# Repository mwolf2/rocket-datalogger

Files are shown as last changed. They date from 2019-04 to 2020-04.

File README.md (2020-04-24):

# rocket-datalogger
Linux-based datalogger for amateur rockets. School project by Max Wolf and Emmett Hart.
Goal -- Make a datalogger that enables amateur rockets to act as low-altitude sounding rockets for meteorological and kinematic data.
Current Status -- Done (for now, might reopen at some point in the future); Contributions Welcome! (please make a pull request)

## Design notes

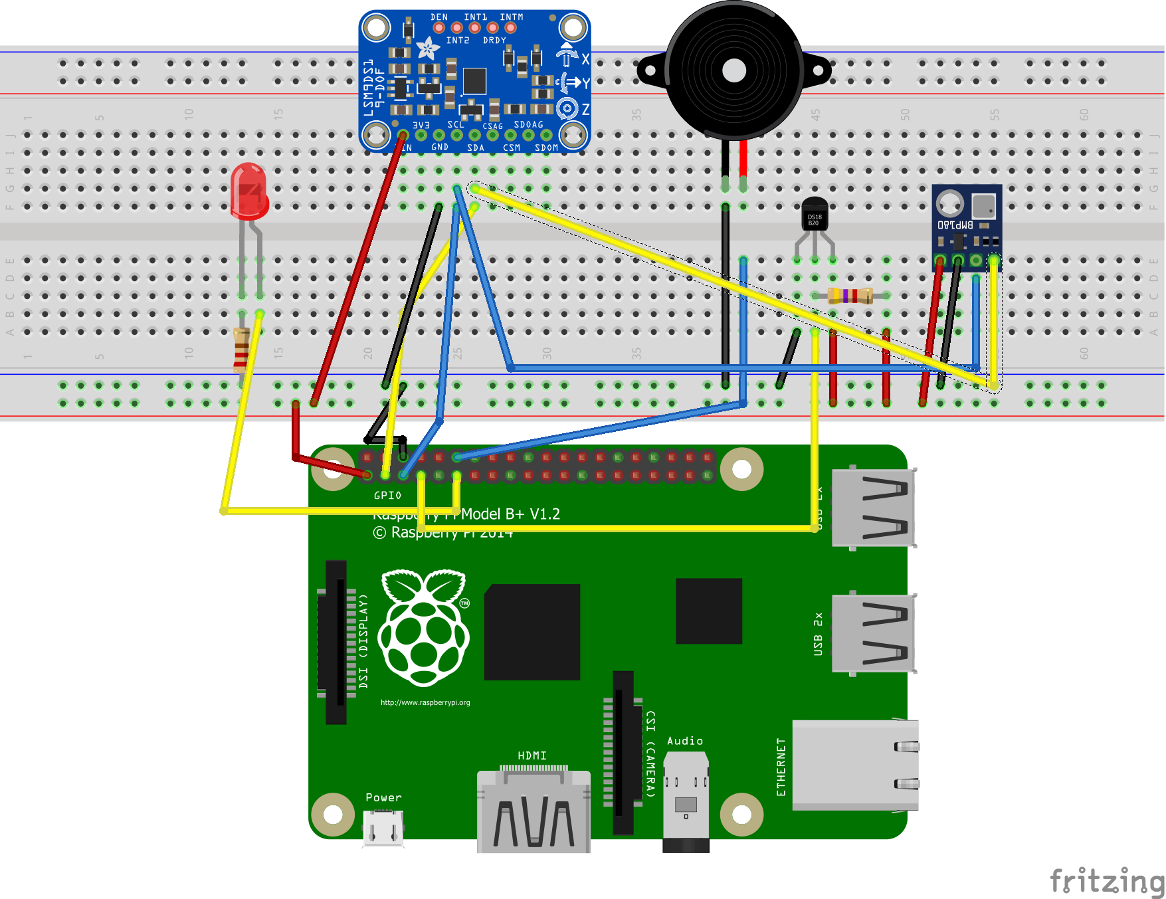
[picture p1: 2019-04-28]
Images/rpi_datalogger_bb.png

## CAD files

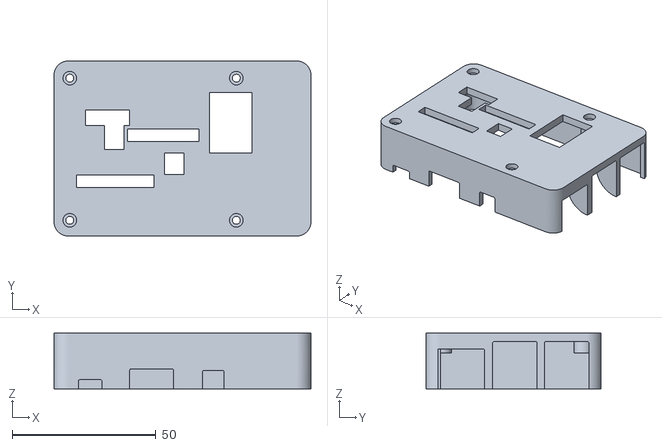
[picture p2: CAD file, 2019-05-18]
3D Models/RPi_Cover_data-logger v4.stl
89.5 x 61.0 x 19.5

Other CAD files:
3D Models/RPi_Cover_data-logger v3.stl
3D Models/RPi_Cover_data-logger v3.f3d
3D Models/RPi_Cover_data-logger v4.f3d

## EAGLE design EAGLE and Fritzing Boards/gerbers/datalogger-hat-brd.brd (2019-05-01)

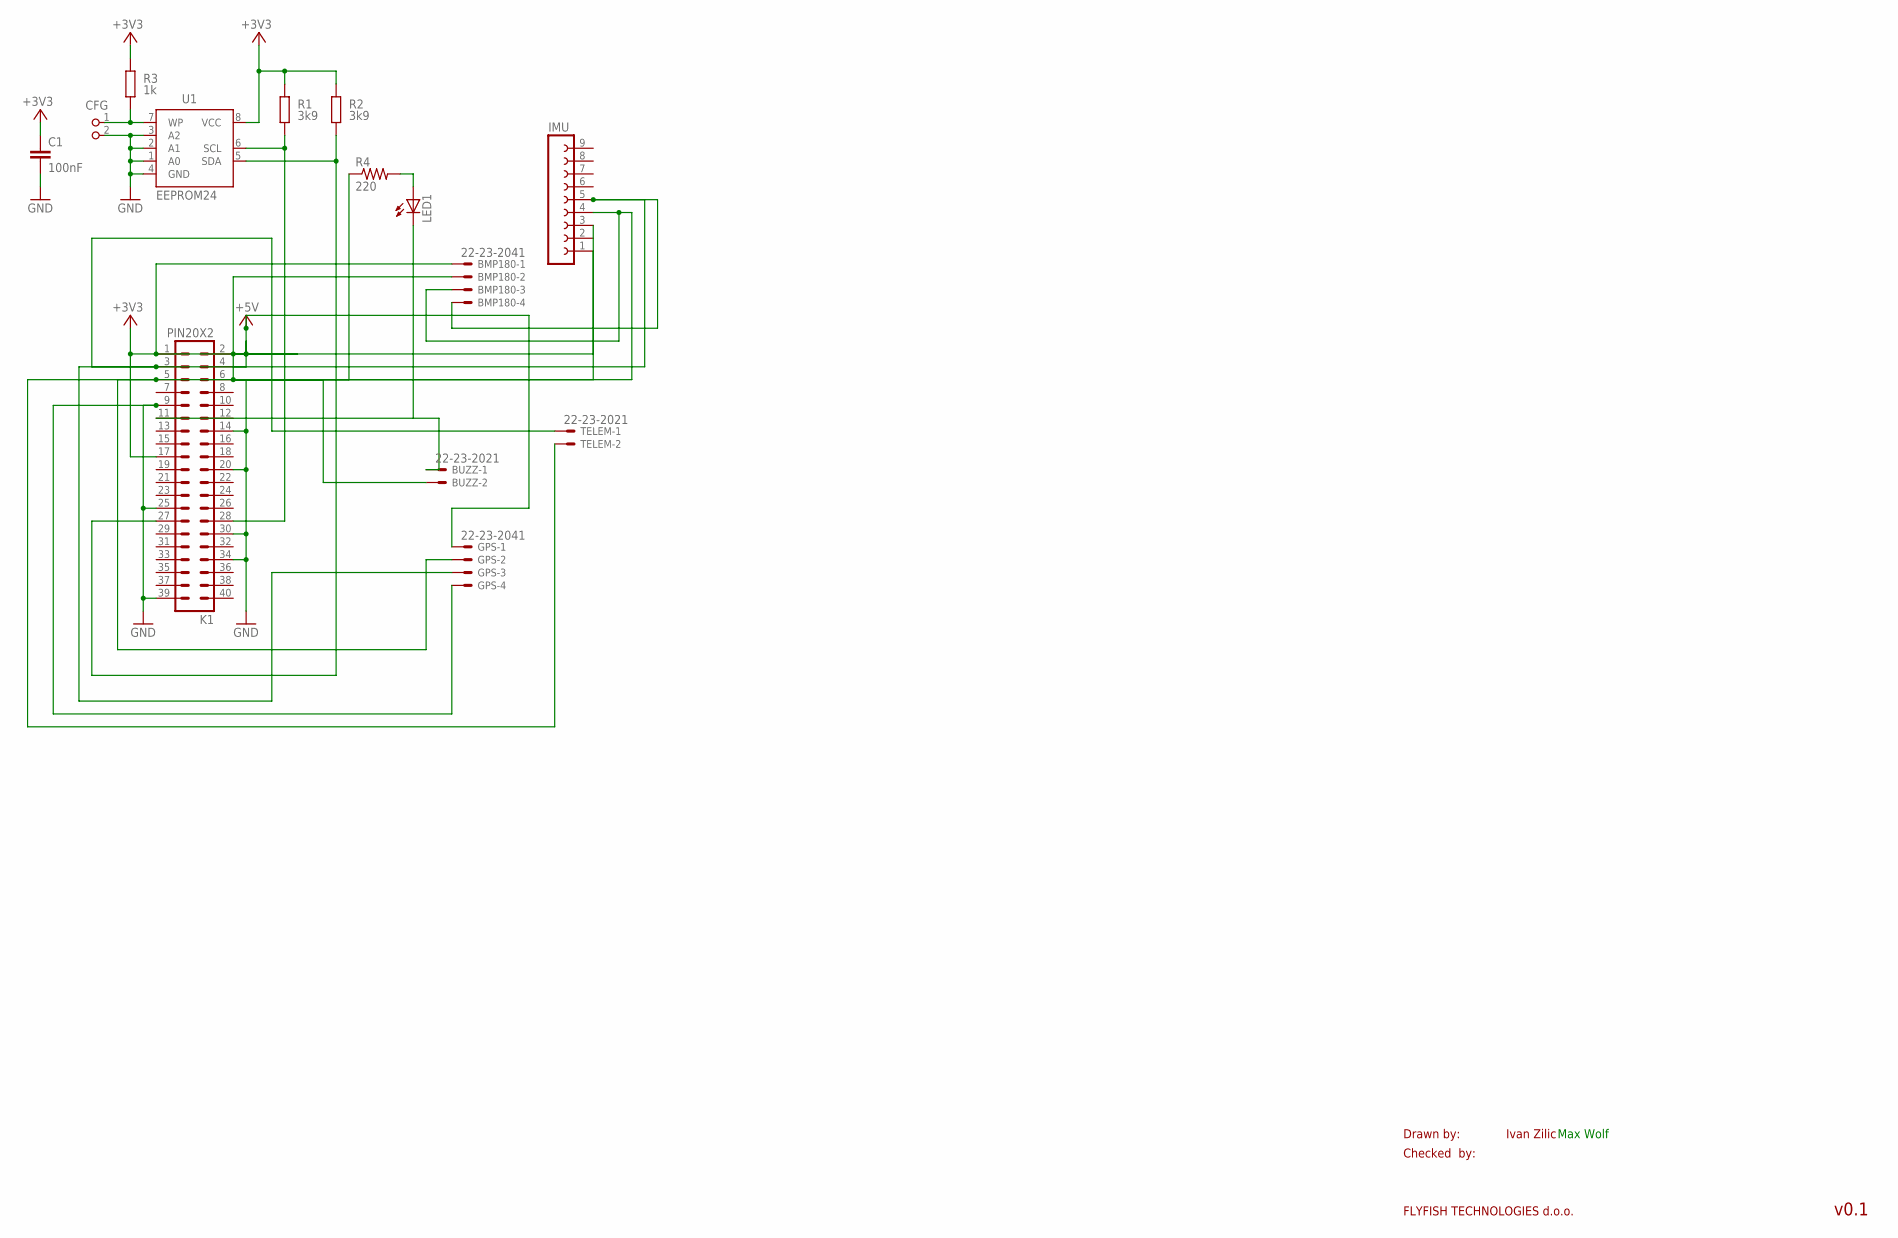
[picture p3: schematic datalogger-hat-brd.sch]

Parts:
BMP180: 22-23-2041
BUZZ: 22-23-2021
C1: 100nF; C0805K
CFG: PIN2_100; PIN_W_2
GPS: 22-23-2041
IMU: FE09-1; FE09
K1: PIN20X2; PIN_20X2
LED1: LED_ELD260; LED_LD260
R1, R2: 3k9; M0805; TOLERANCE 5%
R3: 1k; M0805; TOLERANCE 5%
R4: 220; 0204/5
TELEM: 22-23-2021
U1: EEPROM24; SOIC8

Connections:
+3V3: BMP180.1, C1.1, IMU.1, K1.1, K1.17, R1.2, R2.2, R3.2, U1.8 (VCC)
+5V: GPS.1, K1.2, K1.4
GND: BMP180.2, BUZZ.2, C1.2, CFG.2, GPS.4, IMU.3, K1.6, K1.9, K1.14, K1.20, K1.25, K1.30, K1.34, K1.39, R4.1, U1.1 (A0), U1.2 (A1), U1.3 (A2), U1.4 (GND)
unnamed: K1.28, R1.1, U1.6 (SCL)
unnamed: K1.27, R2.1, U1.5 (SDA)
unnamed: CFG.1, R3.1, U1.7 (WP)
unnamed: BMP180.4, GPS.3, IMU.5, K1.3, TELEM.1
unnamed: BMP180.3, GPS.2, IMU.4, K1.5, TELEM.2
unnamed: BUZZ.1, K1.11, LED1.K (C)
unnamed: LED1.A, R4.2

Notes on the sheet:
Drawn by:
Checked by:
FLYFISH TECHNOLOGIES d.o.o.
Ivan Zilic
v0.1
Max Wolf

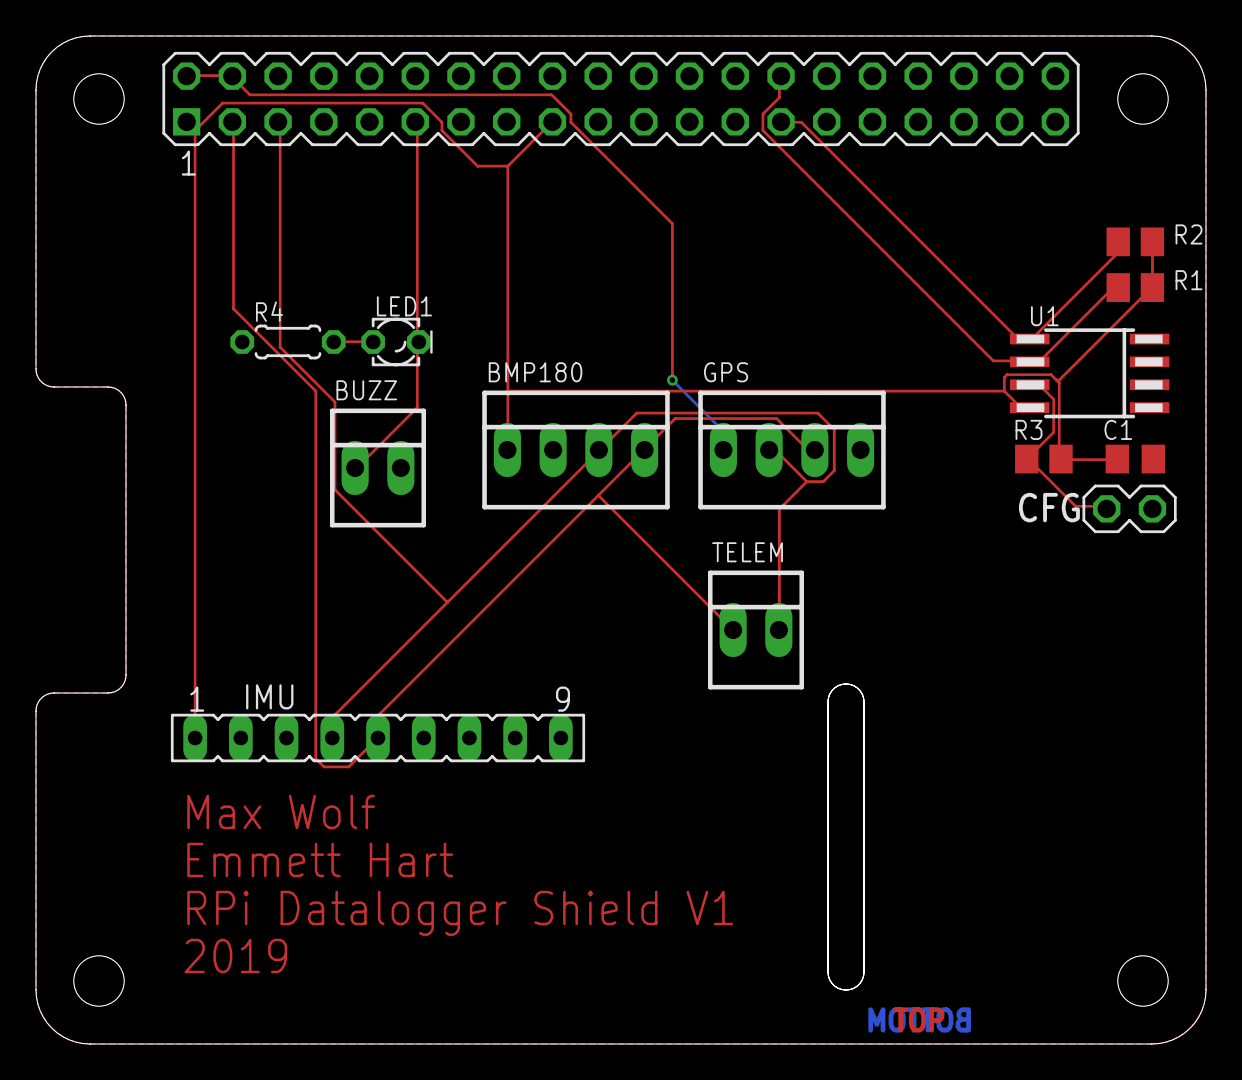
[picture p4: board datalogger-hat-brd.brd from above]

Board: 2 copper layers, 65.0 x 56.0 mm, 14 parts (0 on the bottom side), 10 nets.

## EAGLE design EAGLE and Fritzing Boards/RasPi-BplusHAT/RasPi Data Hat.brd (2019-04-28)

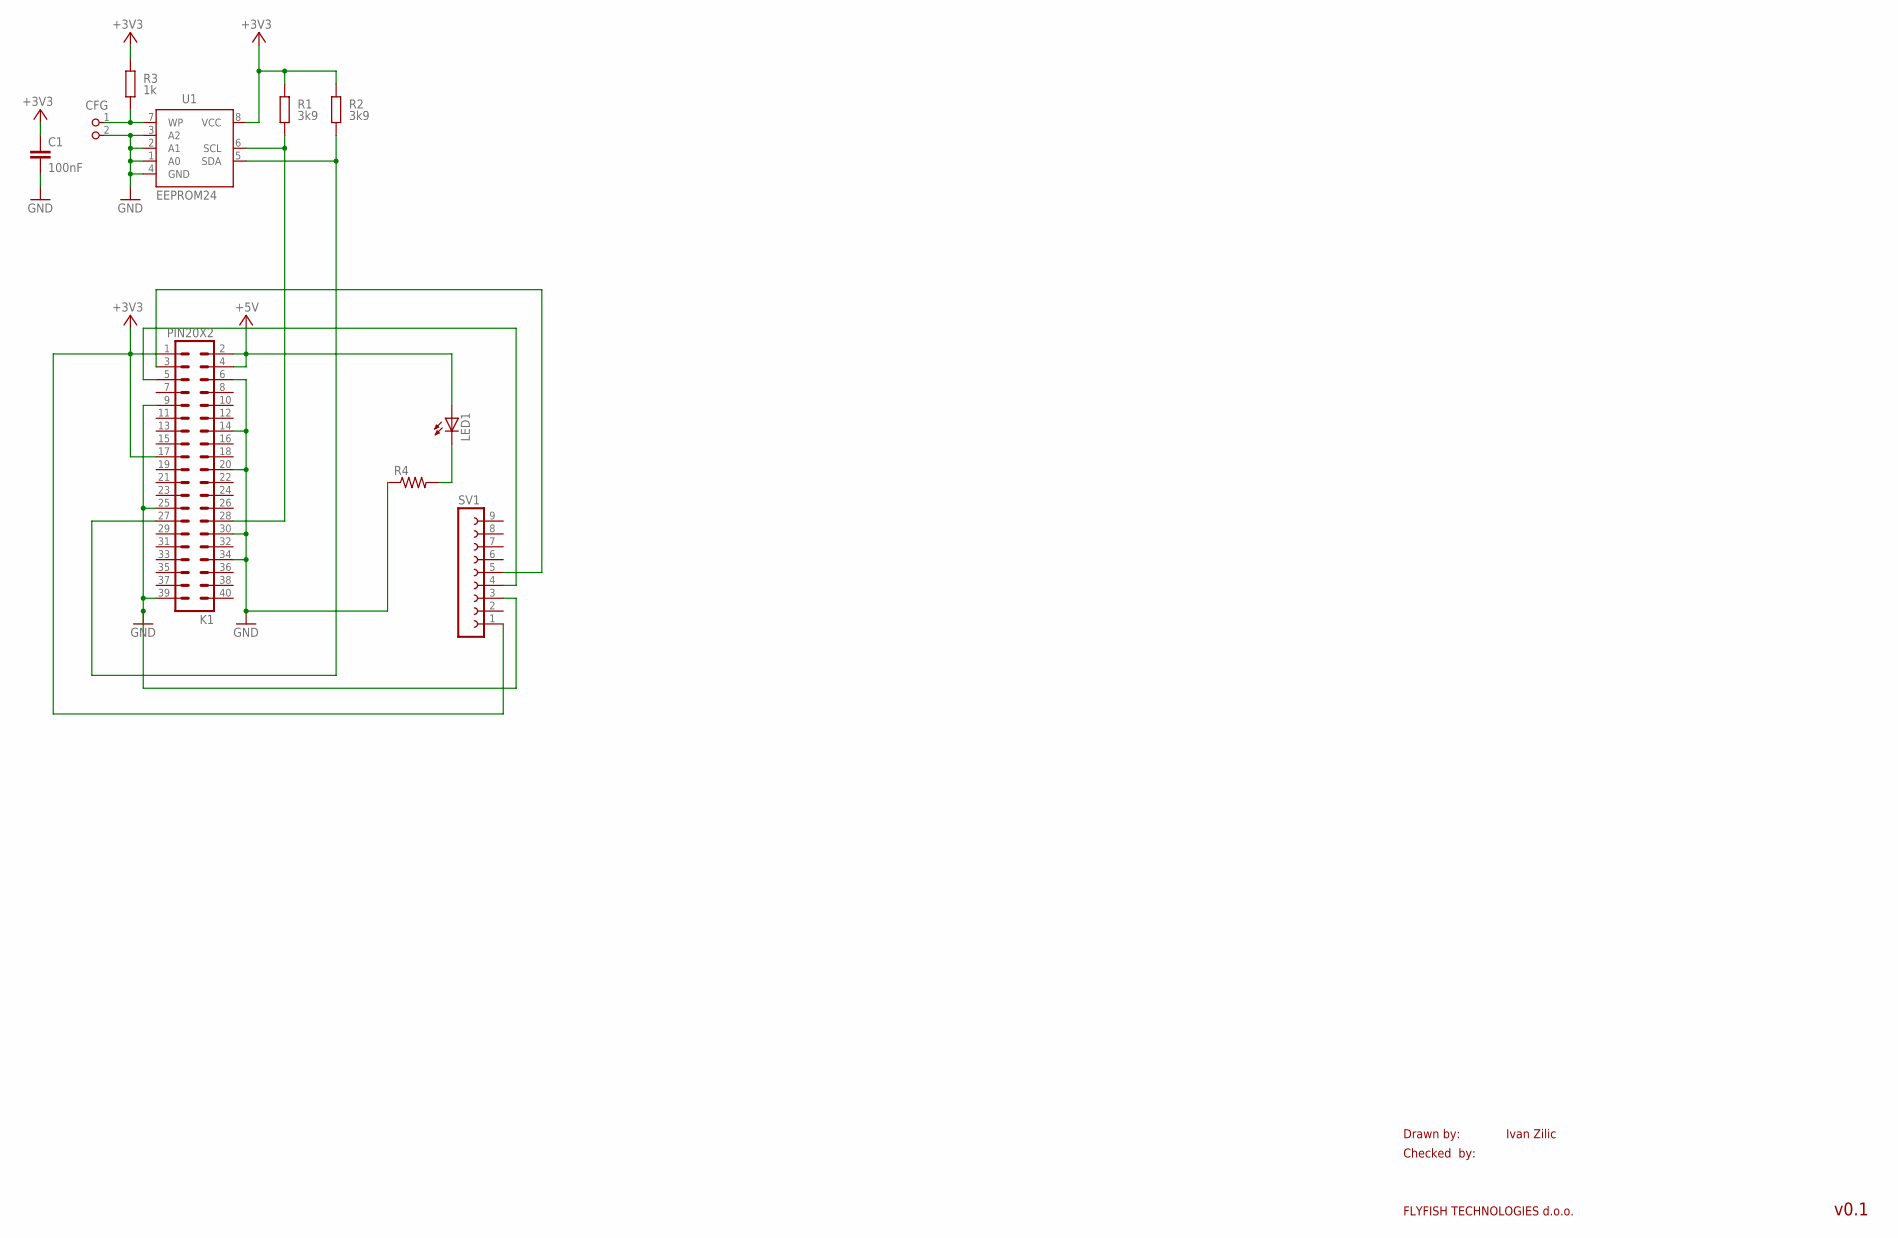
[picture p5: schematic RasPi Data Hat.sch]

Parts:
C1: 100nF; C0805K
CFG: PIN2_100; PIN_W_2
K1: PIN20X2; PIN_20X2
LED1: LED3MM
R1, R2: 3k9; M0805; TOLERANCE 5%
R3: 1k; M0805; TOLERANCE 5%
R4: R-US_0204/5; 0204/5
SV1: FE09-1; FE09
U1: EEPROM24; SOIC8

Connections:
+3V3: C1.1, K1.1, K1.17, R1.2, R2.2, R3.2, SV1.1, U1.8 (VCC)
+5V: K1.2, K1.4, LED1.A
GND: C1.2, CFG.2, K1.6, K1.9, K1.14, K1.20, K1.25, K1.30, K1.34, K1.39, R4.1, SV1.3, U1.1 (A0), U1.2 (A1), U1.3 (A2), U1.4 (GND)
unnamed: K1.28, R1.1, U1.6 (SCL)
unnamed: K1.27, R2.1, U1.5 (SDA)
unnamed: CFG.1, R3.1, U1.7 (WP)
unnamed: LED1.K (C), R4.2
unnamed: K1.5, SV1.4
unnamed: K1.3, SV1.5

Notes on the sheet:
Drawn by:
Checked by:
FLYFISH TECHNOLOGIES d.o.o.
Ivan Zilic
v0.1

Board: 2 copper layers, 10 parts (0 on the bottom side), 9 nets, no tracks yet.

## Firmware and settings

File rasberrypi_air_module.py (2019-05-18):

#Import necessary libraries
#RPi.GPIO necessary to use GPIO pins on RPi
import RPi.GPIO as GPIO
#time library for delays
import time
#smbus necessary to handle I2C communication
import smbus
#subprocess necessary to interact with command line
import subprocess
"""
os necessary to handle interactions with the Pi's operating system.
Additionally, the os library will allow us to make directories, change
directories, handle files, etc.
"""
import os
#datetime necessary to put file timestamps in human-readable format
#Can't use datetime.now() with import datetime. Platform-specific?
from datetime import datetime
#re necessary to get search for text and use it
import re
#BMP180 library
from Adafruit_BMP085 import BMP085
#ctypes for LSM9DS1 library
from ctypes import *
#csv necessary to create csv files
import csv
#itertools needed for islice to read specific lines of CSV
from itertools import islice

#SETUP~~~~~~~~~~~~~~~~~~~~~~~~~~~~~~~~~~~~~~~~~~~~~~~~~~~~~~~~~~~~~~~~~~~~~~~~~

#Pin definitions
ledPin = 17
sdaPin = 2
sclPin = 3
piezoPin = 12

#I2C Port Setup (for communication with Lora boards)
i2c = smbus.SMBus(1)

#I2C Addresses
#Barometer
bmp = BMP085(0x77, 1)
temp = bmp.read_temperature()
pressure = bmp.read_pressure()
asl = bmp.read_altitude() #0m pressure changeable via telemetry later
#IMU
#This code snippet from Akimach on Github:
path = "../lib/liblsm9ds1cwrapper.so"
lib = cdll.LoadLibrary(path)

lib.lsm9ds1_create.argtypes = []
lib.lsm9ds1_create.restype = c_void_p

lib.lsm9ds1_begin.argtypes = [c_void_p]
lib.lsm9ds1_begin.restype = None

lib.lsm9ds1_calibrate.argtypes = [c_void_p]
lib.lsm9ds1_calibrate.restype = None

lib.lsm9ds1_gyroAvailable.argtypes = [c_void_p]
lib.lsm9ds1_gyroAvailable.restype = c_int
lib.lsm9ds1_accelAvailable.argtypes = [c_void_p]
lib.lsm9ds1_accelAvailable.restype = c_int
lib.lsm9ds1_magAvailable.argtypes = [c_void_p]
lib.lsm9ds1_magAvailable.restype = c_int

lib.lsm9ds1_readGyro.argtypes = [c_void_p]
lib.lsm9ds1_readGyro.restype = c_int
lib.lsm9ds1_readAccel.argtypes = [c_void_p]
lib.lsm9ds1_readAccel.restype = c_int
lib.lsm9ds1_readMag.argtypes = [c_void_p]
lib.lsm9ds1_readMag.restype = c_int

lib.lsm9ds1_getGyroX.argtypes = [c_void_p]
lib.lsm9ds1_getGyroX.restype = c_float
lib.lsm9ds1_getGyroY.argtypes = [c_void_p]
lib.lsm9ds1_getGyroY.restype = c_float
lib.lsm9ds1_getGyroZ.argtypes = [c_void_p]
lib.lsm9ds1_getGyroZ.restype = c_float

lib.lsm9ds1_getAccelX.argtypes = [c_void_p]
lib.lsm9ds1_getAccelX.restype = c_float
lib.lsm9ds1_getAccelY.argtypes = [c_void_p]
lib.lsm9ds1_getAccelY.restype = c_float
lib.lsm9ds1_getAccelZ.argtypes = [c_void_p]
lib.lsm9ds1_getAccelZ.restype = c_float

lib.lsm9ds1_getMagX.argtypes = [c_void_p]
lib.lsm9ds1_getMagX.restype = c_float
lib.lsm9ds1_getMagY.argtypes = [c_void_p]
lib.lsm9ds1_getMagY.restype = c_float
lib.lsm9ds1_getMagZ.argtypes = [c_void_p]
lib.lsm9ds1_getMagZ.restype = c_float

lib.lsm9ds1_calcGyro.argtypes = [c_void_p, c_float]
lib.lsm9ds1_calcGyro.restype = c_float
lib.lsm9ds1_calcAccel.argtypes = [c_void_p, c_float]
lib.lsm9ds1_calcAccel.restype = c_float
lib.lsm9ds1_calcMag.argtypes = [c_void_p, c_float]
lib.lsm9ds1_calcMag.restype = c_float

if __name__ == "__main__":
    imu = lib.lsm9ds1_create()
    lib.lsm9ds1_begin(imu)
    if lib.lsm9ds1_begin(imu) == 0:
        print("Failed to communicate with LSM9DS1.")
        quit()
    lib.lsm9ds1_calibrate(imu)

    while True:
        while lib.lsm9ds1_gyroAvailable(imu) == 0:
            pass
        lib.lsm9ds1_readGyro(imu)
        while lib.lsm9ds1_accelAvailable(imu) == 0:
            pass
        lib.lsm9ds1_readAccel(imu)
        while lib.lsm9ds1_magAvailable(imu) == 0:
            pass
        lib.lsm9ds1_readMag(imu)

        gx = lib.lsm9ds1_getGyroX(imu)
        gy = lib.lsm9ds1_getGyroY(imu)
        gz = lib.lsm9ds1_getGyroZ(imu)

        ax = lib.lsm9ds1_getAccelX(imu)
        ay = lib.lsm9ds1_getAccelY(imu)
        az = lib.lsm9ds1_getAccelZ(imu)

        mx = lib.lsm9ds1_getMagX(imu)
        my = lib.lsm9ds1_getMagY(imu)
        mz = lib.lsm9ds1_getMagZ(imu)

        cgx = lib.lsm9ds1_calcGyro(imu, gx)
        cgy = lib.lsm9ds1_calcGyro(imu, gy)
        cgz = lib.lsm9ds1_calcGyro(imu, gz)

        cax = lib.lsm9ds1_calcAccel(imu, ax)
        cay = lib.lsm9ds1_calcAccel(imu, ay)
        caz = lib.lsm9ds1_calcAccel(imu, az)

        cmx = lib.lsm9ds1_calcMag(imu, mx)
        cmy = lib.lsm9ds1_calcMag(imu, my)
        cmz = lib.lsm9ds1_calcMag(imu, mz)
#End Akimach's code
#Tell console I2C device list is about to be printed
print("I2C Device List:")
#Open terminal, run i2cdetect
geti2c = subprocess.Popen(['i2cdetect', '-y', '1'], stdout=subprocess.PIPE)
#For every match for number, number: anything, number, number found, print it
"""
Add feature that lets RPi check that Lora, baro, and IMU are at certain
addresses
"""
for i in range (0,9):
    line = str(p.stdout.readline())
    
    for match in re.finditer("[0-9][0-9]:.*[0-9][0-9]", line):
        #match.group() is all i2c devices from i2cdetect
        i2cDev = match.group()
        #Parse i2cDev so that we get rid of dashes and spaces
        i2cDevParsed = i2cDev.replace("-", "").replace(" ", "") #Bad syntax
        #Print out the result
        print (i2cDevParsed, "\n")
        
        
#Set up LoraWAN board through I2C
loraAddress = 0x04

def sendByte(x):
    i2c.write_byte(loraAddress, x)
    return -1

def recByte():
    inByte = i2c.read_byte(loraAddress)
    return inByte

sendByte(0)
print ('Sent Lora board "0"')

loraOpenByte = recByte()
print ('Received ', loraOpenByte, ' from Lora board.\n')

if loraOpenByte == 1:
    print ('Connection with Lora board established.')
else:
    print ('No connection to Lora board.')

"""
Set RPi GPIO mode - in this case, we are referring to the RPi's GPIO pins
according to the numbering printed on the motherboard. This is because the
datalogger doesn't use a Pi Wedge or similar device, so it's just easier
this way.
"""
GPIO.setmode(GPIO.BOARD)

print("GPIO mode set to BOARD") #Print GPIO mode to command line

GPIO.setup(ledPin, GPIO.OUT) #LED pin set to output
GPIO.setup(piezoPin, GPIO.OUT) #Piezo pin set to output

#Set up CSV
timestamp = datetime.now().strftime('%Y-%m-%d-%H-%M')
filetime = timestamp.replace("'", "")
dataCSV = "flightdata " + filetime + ".csv" #Set up CSV name for datalogging

titleRow = ['Time', 'Xa', 'Ya', 'Za', 'Xo', 'Yo', 'Zo', 'Mx', 'My', 'Mz', 'Pressure', 'ASL', 
            'AGL', 'Temp']

with open(dataCSV, 'w'):
    writer = csv.writer(dataCSV)
    writer.writerow(titleRow)
    
dataCSV.close()

#Setup is finished! On to the datalogging and telemetry

#Datalogging & Telemetry~~~~~~~~~~~~~~~~~~~~~~~~~~~~~~~~~~~~~~~~~~~~~~~~~~~~~~~
print("Beginning logging and telemetry transmission.")


landed = 0 #Rocket landed -- Controls what is being sent
flightComplete = 0 #Flight complete, datalogging can stop
landTimerStarted = 0
landTimeElapsed = 0

calibration = open('calibration' + datetime.now().strftime('%Y-%m-%d-%H-%M'), 'w')
calibration.write(asl + "\n")
calibration.write()

rowCount = 1;

while (flightComplete == 0):
    
    with open(calibration, "r"):
        calReadAlt = calibration.readline(1)
        agl = asl - calReadAlt
    
    ltime = datetime.now().strftime('%H-%M')
    dataRow = [ltime, cax, cay, caz, cgx, cgy, cgz, cmx, cmy, cmz, pressure,
               asl, agl]
    
    with open(dataCSV, 'a'):
        writer = csv.writer(dataCSV)
        writer.writerow(dataRow)
        rowCount += 1
    
    with open(dataCSV, "r"):
        dataRead = csv.reader(dataCSV, delimiter = ',')
        for row in reversed(dataRead):
            lastAlt = row[12]
            if (lastAlt == asl):
                if (landTimerStarted == 0):
                    landStart = time.time()
                else:
                    landCurrent = time.time()
                    landTimeElapsed = landStart - landCurrent
                    if (landTimeElapsed == 30):
                        flightComplete = 1
                
            else:
                pass

dataCSV.close()

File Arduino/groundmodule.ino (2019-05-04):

#include <U8x8lib.h>
#include <LoRa.h>

String receivedT;
String receivedRSSI;

//GPIO19 - LoRa_MISO
//GPIO18 - LoRa_CS
//GPIO5 - LoRa_SCK
//GPIO27 - LoRa_MOSI
//GPIO14 - LoRa_RST

#define SS  18 //Slave Select
#define RST 14
#define DI0 26

void setup() {

  int counter = 0;
  int conTimer = 0;
  bool conOK = 1;
  Serial.begin(115200);
  while(!Serial);
  LoRa.setPins(SS, RST, DI0);

  while (!LoRa.begin(868E6) && conOK == 1)
  {
    Serial.println(".");
    delay(1000);
    conTimer++;

    if (conTimer > 20)
    {
      conOK = 0;
      Serial.println("No connection to rocket.");
    }
    
  }
  

  LoRa.setSyncWord(0xF3);
  LoRa.beginPacket();
  LoRa.print("OK");
  LoRa.print(counter);
  LoRa.endPacket();

}

void loop() {
  

}

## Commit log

2019-04-27 Add files via upload
    First project commit outside of when repository was created. Includes EAGLE and Fritzing boards, images, and programs as of 4/27/2019 at 11:33AM GMT
2019-04-28 Add files via upload
    Committed more recent files to master branch, and not in .zip format. 5:18PM GMT
    [RasPi Data Hat.brd, RasPi Data Hat.sch, RasPi-BplusHAT.brd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]
2019-05-01 Rename EAGLE and Fritzing Boards/copper_bottom.gbr to EAGLE and Fritzing Boards/gerbers/copper_bottom.gbr
    [copper_bottom.gbr]
2019-05-01 Rename EAGLE and Fritzing Boards/copper_top.gbr to EAGLE and Fritzing Boards/gerbers/copper_top.gbr
    [copper_top.gbr]
2019-05-01 Rename EAGLE and Fritzing Boards/datalogger-hat-brd.brd to EAGLE and Fritzing Boards/gerbers/datalogger-hat-brd.brd
    [datalogger-hat-brd.brd]
2019-05-01 Rename EAGLE and Fritzing Boards/datalogger-hat-brd.sch to EAGLE and Fritzing Boards/gerbers/datalogger-hat-brd.sch
    [datalogger-hat-brd.sch]
2019-05-01 Rename EAGLE and Fritzing Boards/drills.xln to EAGLE and Fritzing Boards/gerbers/drills.xln
    [drills.xln]
2019-05-01 Rename EAGLE and Fritzing Boards/gerber_job.gbrjob to EAGLE and Fritzing Boards/gerbers/gerber_job.gbrjob
    [gerber_job.gbrjob]
2019-05-01 Rename EAGLE and Fritzing Boards/profile.gbr to EAGLE and Fritzing Boards/gerbers/profile.gbr
    [profile.gbr]
2019-05-01 Rename EAGLE and Fritzing Boards/silkscreen_bottom.gbr to EAGLE and Fritzing Boards/gerbers/silkscreen_bottom.gbr
    [silkscreen_bottom.gbr]
2019-05-01 Rename EAGLE and Fritzing Boards/silkscreen_top.gbr to EAGLE and Fritzing Boards/gerbers/silkscreen_top.gbr
    [silkscreen_top.gbr]
2019-05-01 Rename EAGLE and Fritzing Boards/soldermask_bottom.gbr to EAGLE and Fritzing Boards/gerbers/soldermask_bottom.gbr
    [soldermask_bottom.gbr]
2019-05-01 Rename EAGLE and Fritzing Boards/soldermask_top.gbr to EAGLE and Fritzing Boards/gerbers/soldermask_top.gbr
    [soldermask_top.gbr]
2019-05-01 Rename EAGLE and Fritzing Boards/solderpaste_bottom.gbr to EAGLE and Fritzing Boards/gerbers/solderpaste_bottom.gbr
    [solderpaste_bottom.gbr]
2019-05-01 Rename EAGLE and Fritzing Boards/solderpaste_top.gbr to EAGLE and Fritzing Boards/gerbers/solderpaste_top.gbr
    [solderpaste_top.gbr]
2019-05-10 Updated raspberrypi_air_module.py to export CSV File and add lib/
2019-05-10 finished CSV export support, need to fix AGL logging
    [rasberrypi_air_module.py]
2019-05-10 Forgot to run program to test after last commit, accidentally removed dependancy, Although I don't think we need that section of code anyways (calibration file)
2019-05-11 added Raspberry Pi case
    [RPi_Cover_data-logger v3.f3d, RPi_Cover_data-logger v3.stl]
2019-05-11 Updated pin length
    [RPi_Cover_data-logger v4.f3d, RPi_Cover_data-logger v4.stl]
2019-05-18 Fixed directory problems (as long as Pi Programs and lib are next to each other) and added a file of successful data).
    [raspberrypi_air_module.py]
2019-05-20 Added an Alpha Beta filter and more plots.
